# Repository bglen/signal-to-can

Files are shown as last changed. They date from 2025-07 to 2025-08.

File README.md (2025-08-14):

# signal-to-can device

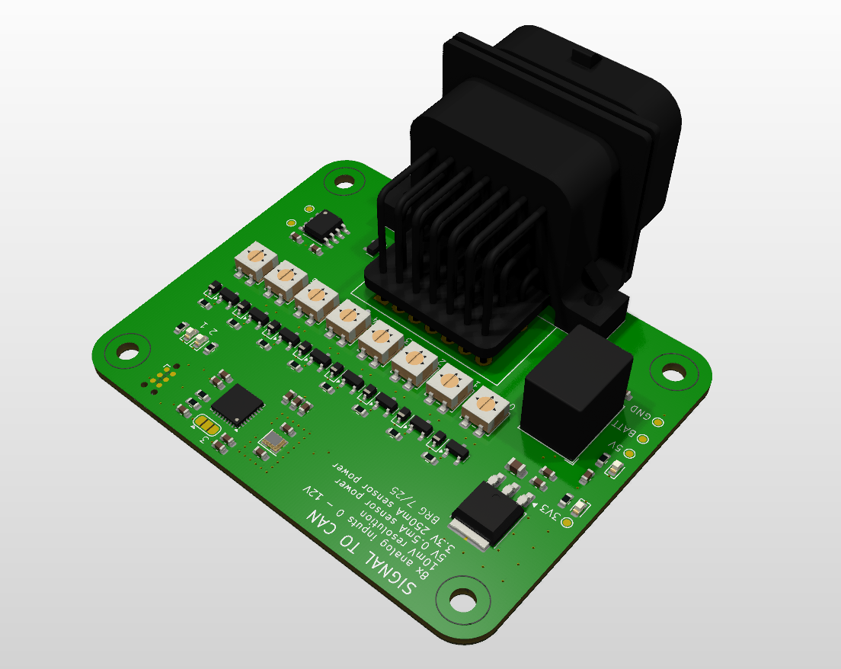
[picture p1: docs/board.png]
PCB view of device


Measures analog and digital signals and converts readings to CAN bus messages. Easilly powered by 12V automotive systems to make CAN bus datalogging in your vehicle easy.

- 8 ADC inputs with seperate signal grounds
  
- CAN 2.0b communication output
  
- Fully configurable through the CAN interface
  
- 3.3V and 5V sensor power supply
  
- Easilly powered by 12V automotive systems

- Per-channel configurable voltage offset and scaling

- Per-channel configurable out-of-range limits

- Pre-made DBC file you can use or edit as a template

### Enclosure

The repo contains a 3D-printable enclosure. We reccomend ASA, ABS, PC-ABS, or Nylon for automotive enviornments.

Front            |  Rear
:-------------------------:|:-------------------------:
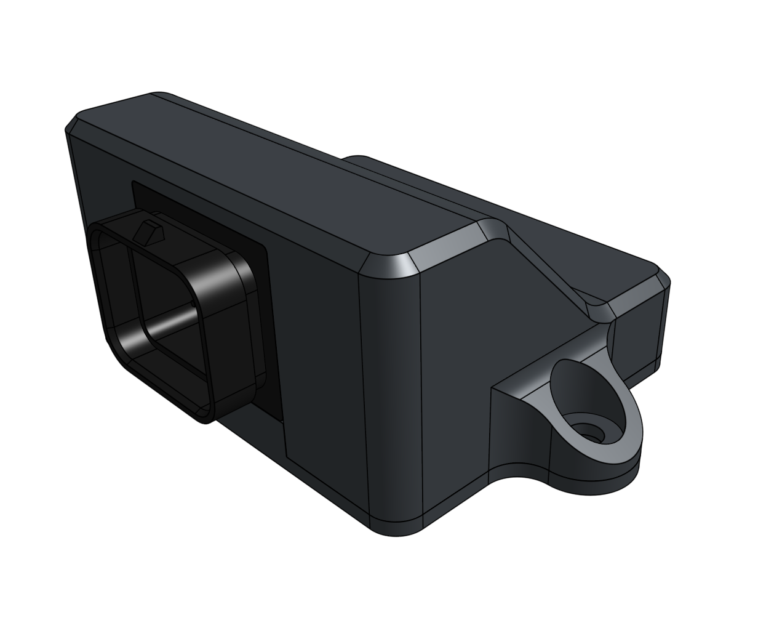
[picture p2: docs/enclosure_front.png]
Enclosure front
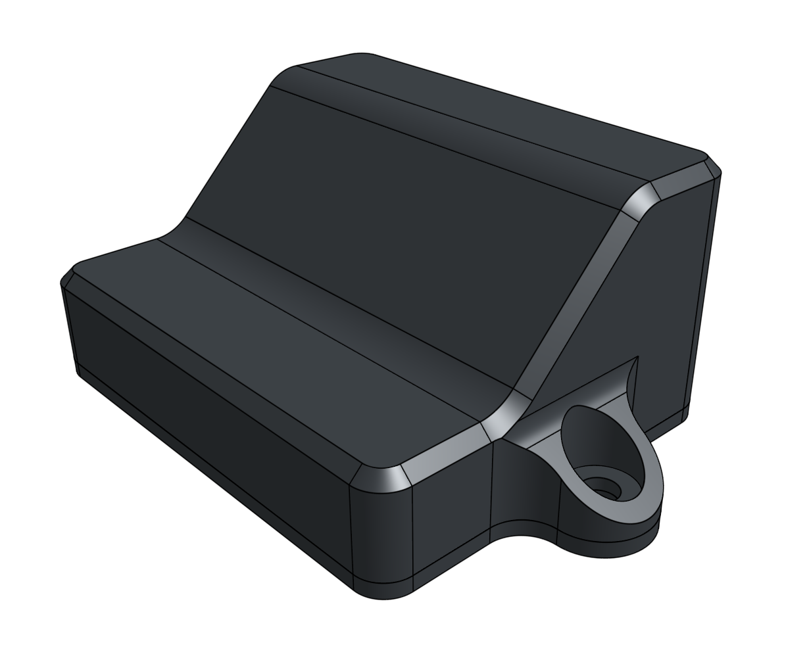
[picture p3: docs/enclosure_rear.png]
Enclosure rear
  |  

### TODO
- Update board with schematic changes
- Calibration test points
- Choose new potentiometer for rev 2
- configuration CAN message

# CAN Messages

All messages are big-endian (Motorola).

## Output Messages

| Name | ID | DLC | Bytes 0-1 | Bytes 2-3 | Bytes 4-5 | Bytes 6-7 |
| --- | --- | --- | --- | --- | --- | --- |
| ADC Values 0 - 3 | node_id + 0x1 | 8 bytes | adc_0 | adc_1 | adc_2 | adc_3 |
| ADC Values 4 - 7 | node_id + 0x2 | 8 bytes | adc_4 | adc_5 | adc_6 | adc_7 |

| Name | ID | DLC | Bytes 0-1  | Bytes 2-3 | Bytes 4-5 | Bytes 6-7  |
| --- | --- | --- | --- | --- | --- | --- |
| Device Status | node_id + 0x3 | 8 bytes | adc_status | uptime | v_supply  | fw_version |

### Parameters

**adc_0 to adc_7:** uint16, ontains the output value for each analog channel.

**adc_status:** uint16, Bit structure containing the current status for each channel. Each channel gets two bits starting with channel 0 to channel 7.

| 2-bit value  | Status |
| ---  | --- |
| 00 | Inactive |
| 01 | Active |
| 10 | Out-of-range low  |
| 11 | Out-of-range high |

Example: adc_satus = 00011001010111 -> channel 0 inactive, channel 1 active, channel 3 out-of-range low, channel 4 active, channel 5 active, channel 6 active, channel 7 out-of-range high.

**uptime:** uint16, Seconds since power-on, wraps at 65535.

**v_supply:** uint16, Device supply voltage in mV.

**fw_version** uint16, Device firmware version.

## Command Message

A single CAN ID is used for all command messages. The device will respond with an acknoledge message after receiving the command message.

| Name | ID | DLC | Byte 0  | Byte 1 | Byte 2 | Byte 3 | Byte 4 | Byte 5 | Byte 6 | Byte 7 |
| --- | --- | --- | --- | -----  | -----  | -----  | -----  | -----  | -----  | -----  |
| Command Message | node_id + 0x5 | 8 bytes | com | d1 | d2 | d3 | d4 | d5 | d6 | d7 |
| Ack Message | node_id + 0x6 | 1 bytes | success | | | | | | | |

### Command Codes

| Command Name | Command Code (com) | d1 | d2 | d3 | d4 | d5 | d6 | d7 |
| --- | --- | --- | --- | --- | --- | --- | --- | -- |
| SET_BAUD | 1 | baud_enum | 0 | 0 | 0 | 0 | 0 | 0  |
| SET_SAMPLE_RATE | 2 | sample_rate[0] | sample_rate[1] | 0 | 0 | 0 | 0 | 0  |
| SET_CHANNEL | 3 | channel | enable_bit | scale_factor[0] | scale_factor[1] | offset[0]  | offset[1] | 0  |
| SET_CHANNEL_RANGE  | 4 | channel | oor_min[0] | oor_min[1] | oor_max[0] | oor_max[1] | 0 | 0  |
| GET_VALUE | 5 | channel | selection | 0 | 0 | 0 | 0 | 0  |

### Parameters

**com:** uint8, Command code. Use the table below to specify a particular command and structure the data

**d1 to d5 :** unint8, Command-specific data.

**success:** uint8, 1 if command executed successfully, 0 if there was an error.

**baud_enum:** uint8, Enum representing the desired baud rate.

| baud_enum | Baud Rate |
| --- | --- |
| 0 | 125 kbps  |
| 1 | 250 kbps  |
| 2 | 500 kbps  |
| 3 | 1 Mbps |

**sample_rate:** uint16, Sample rate of the device in Hz. All channels are sampled at the same rate.

**channel:** uint8, Channel number from 0 to 7.

**enable_bit:** uint8, 0 -> inactive, 1 -> active.

**scale_factor:** uint16, Scale factor to convert the channel voltage to a useful value.

**offset:** uint16, Channel offset value, used with scale factor to convert the channel voltage to a useful value.

**oor_min:** uint16, Out of range minimum value. Used to detect issues with the channel, wiring, or sensor. Specify as a voltage in milivolts, from 0 to 3300. Must be less than the oor_max for that channel.

**oor_max:** uint16, Out of range maximum value. Used to detect issues with the channel, wiring, or sensor. Specify as a voltage in milivolts, from 0 to 3300.

**selection:** uint8, Enum representing the desired value to be returned.

| selection | Value to be returned |
| --- | --- |
| 0 | sample_rate |
| 1 | scale_factor |
| 2 | offset |
| 3 | oor_min |
| 4 | oor_max |

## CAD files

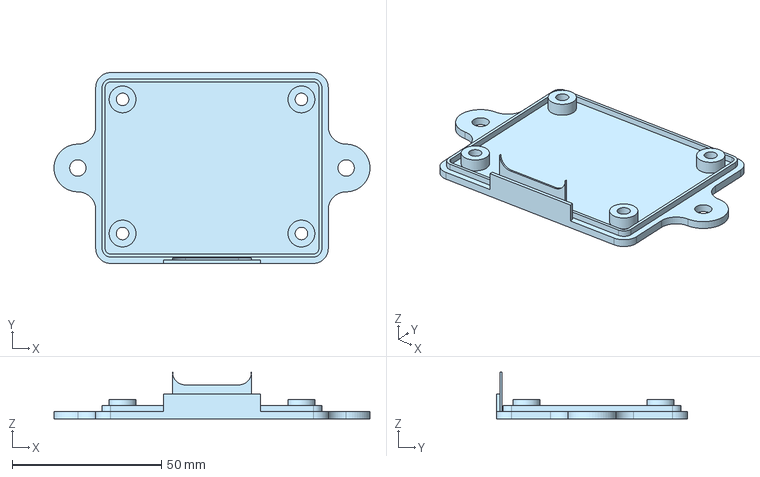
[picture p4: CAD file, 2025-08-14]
hardware/cad/base.step
106.0 x 64.0 x 15.7 mm

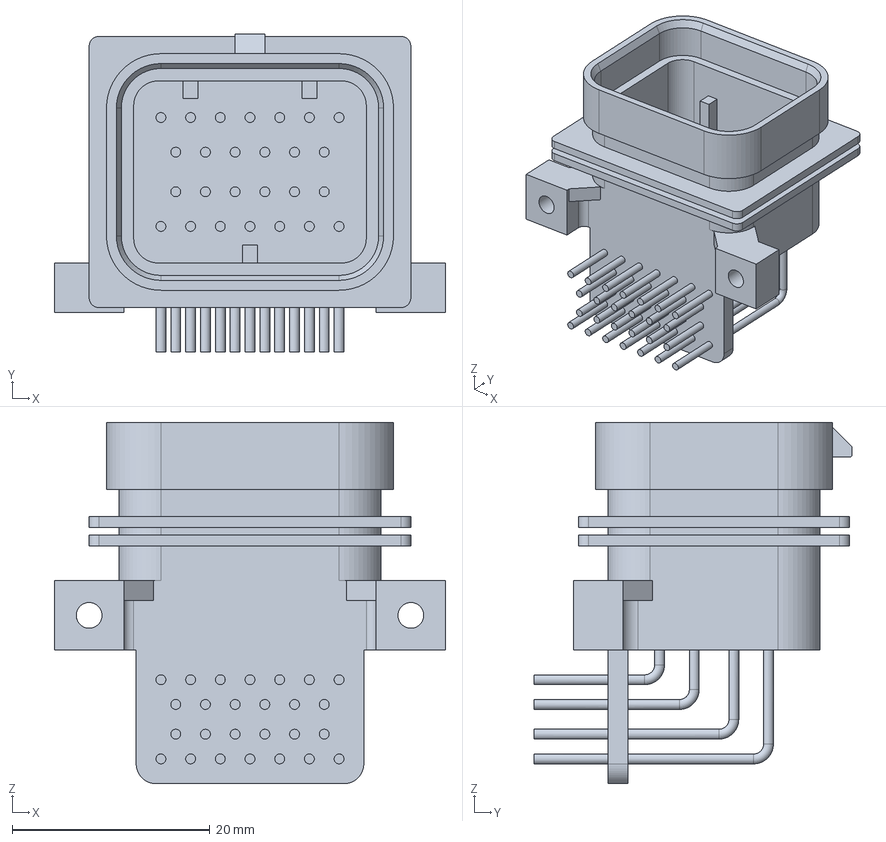
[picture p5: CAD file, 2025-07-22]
hardware/signal-to-can/3d_models/amp_superseal_9-6437287-8.step
39.5 x 32.1 x 36.5 mm

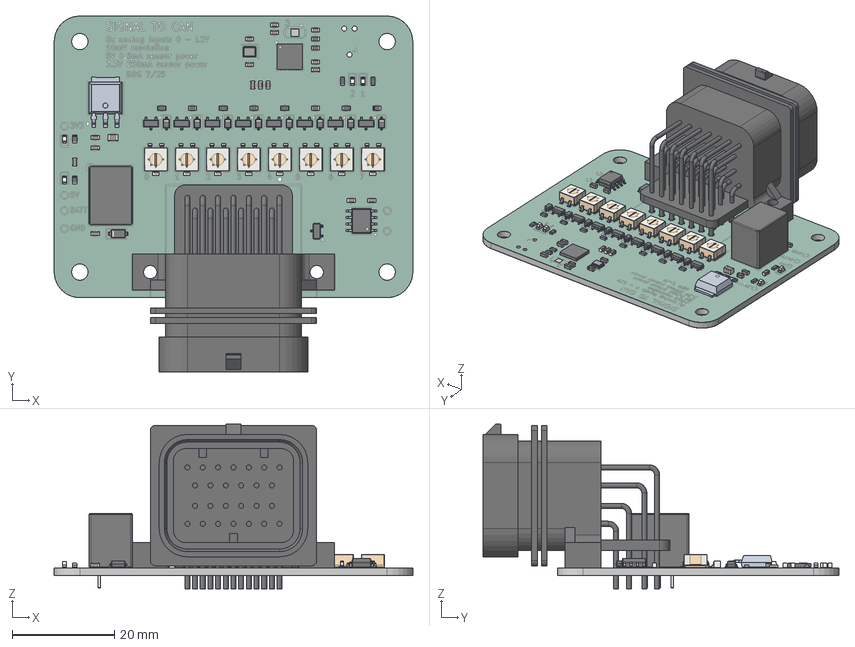
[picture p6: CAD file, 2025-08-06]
hardware/signal-to-can/signal-to-can.step
70.0 x 69.5 x 32.2 mm
D_SOD-323 x 8
Potentiometer_Bourns_3314G_Vertical x 8
LED_0603_1608Metric x 4
R_0603_1608Metric x 14
SOIC-8_3.9x4.9mm_P1.27mm
C_0603_1608Metric x 16
SOT-23 x 9
QFN-32-1EP_5x5mm_P0.5mm_EP3.45x3.45mm
D_SOD-123
C_0805_2012Metric
amp_superseal_9-6437287-8
signal-to-can 1.49.1
Crystal_SMD_2520-4Pin_2.5x2.0mm
Converter_DCDC_RECOM_R-78E-0.5_THT
signal-to-can_silkscreen
signal-to-can_soldermask
signal-to-can_PCB

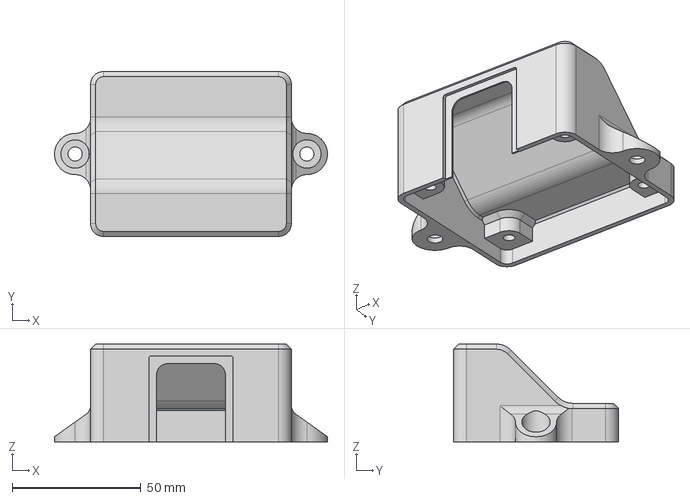
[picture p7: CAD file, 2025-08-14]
hardware/cad/lid.step
106.0 x 64.0 x 38.0 mm

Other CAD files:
hardware/cad/base.stl
hardware/cad/lid.stl

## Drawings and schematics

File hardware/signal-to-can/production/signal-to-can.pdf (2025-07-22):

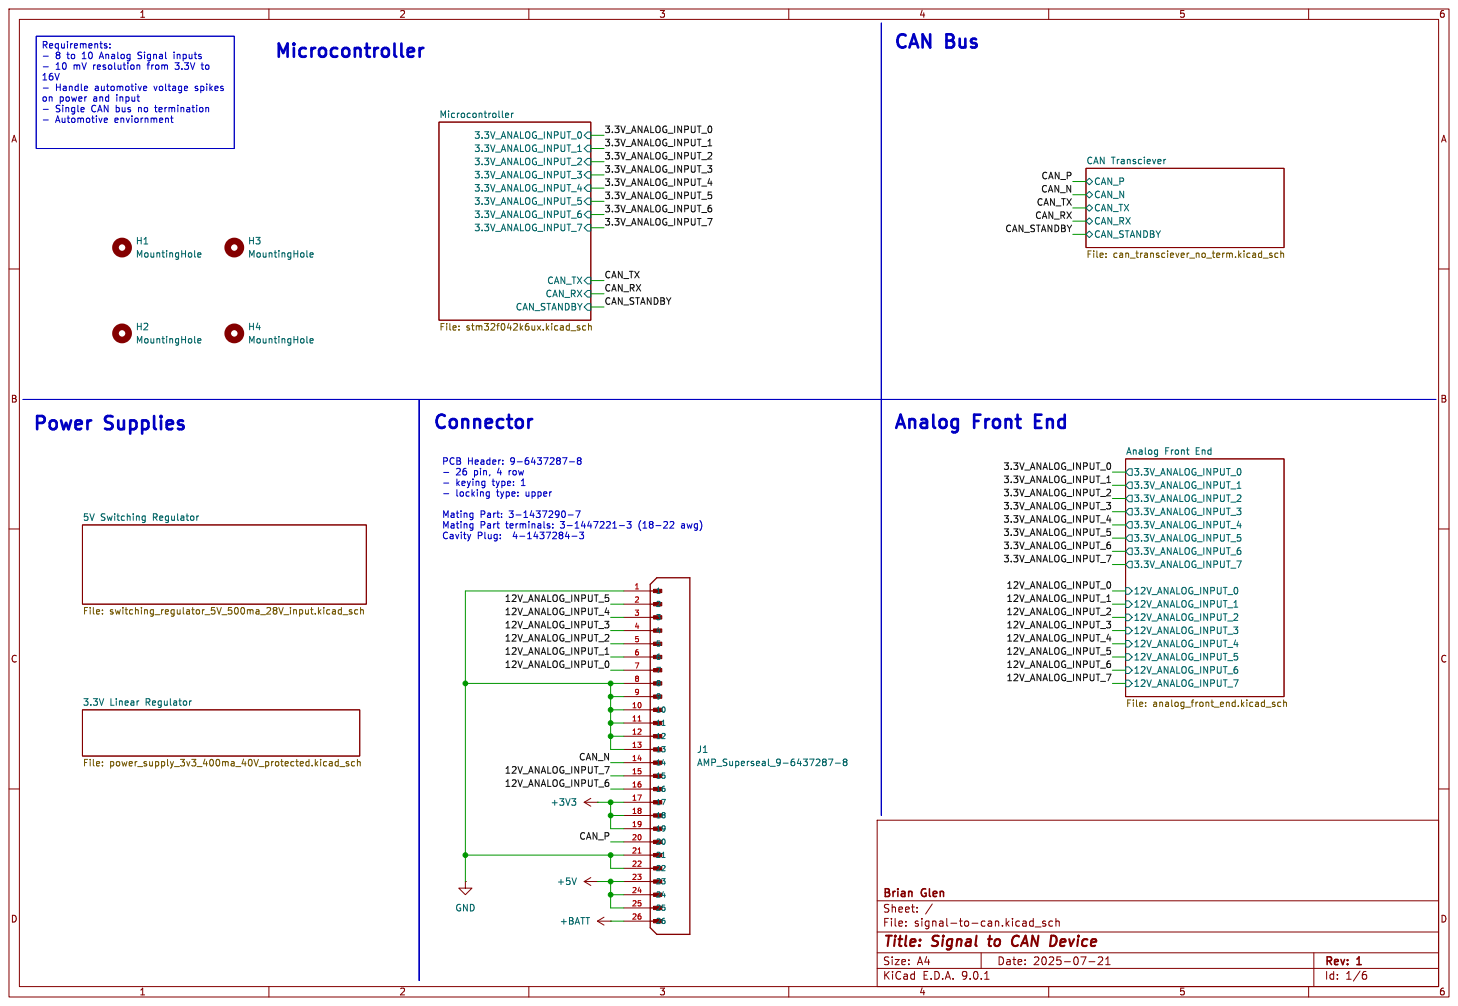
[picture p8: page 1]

3.3V_ANALOG_INPUT_1 Requirements: - 8 to 10 Analog Signal inputs

12V_ANALOG_INPUT_0 Analog Front End File: analog_front_end.kicad_sch +3V3 +BATT

File: signal-to-can.kicad_sch Sheet: / Brian Glen

Id: 1/6 Title: Signal to CAN Device

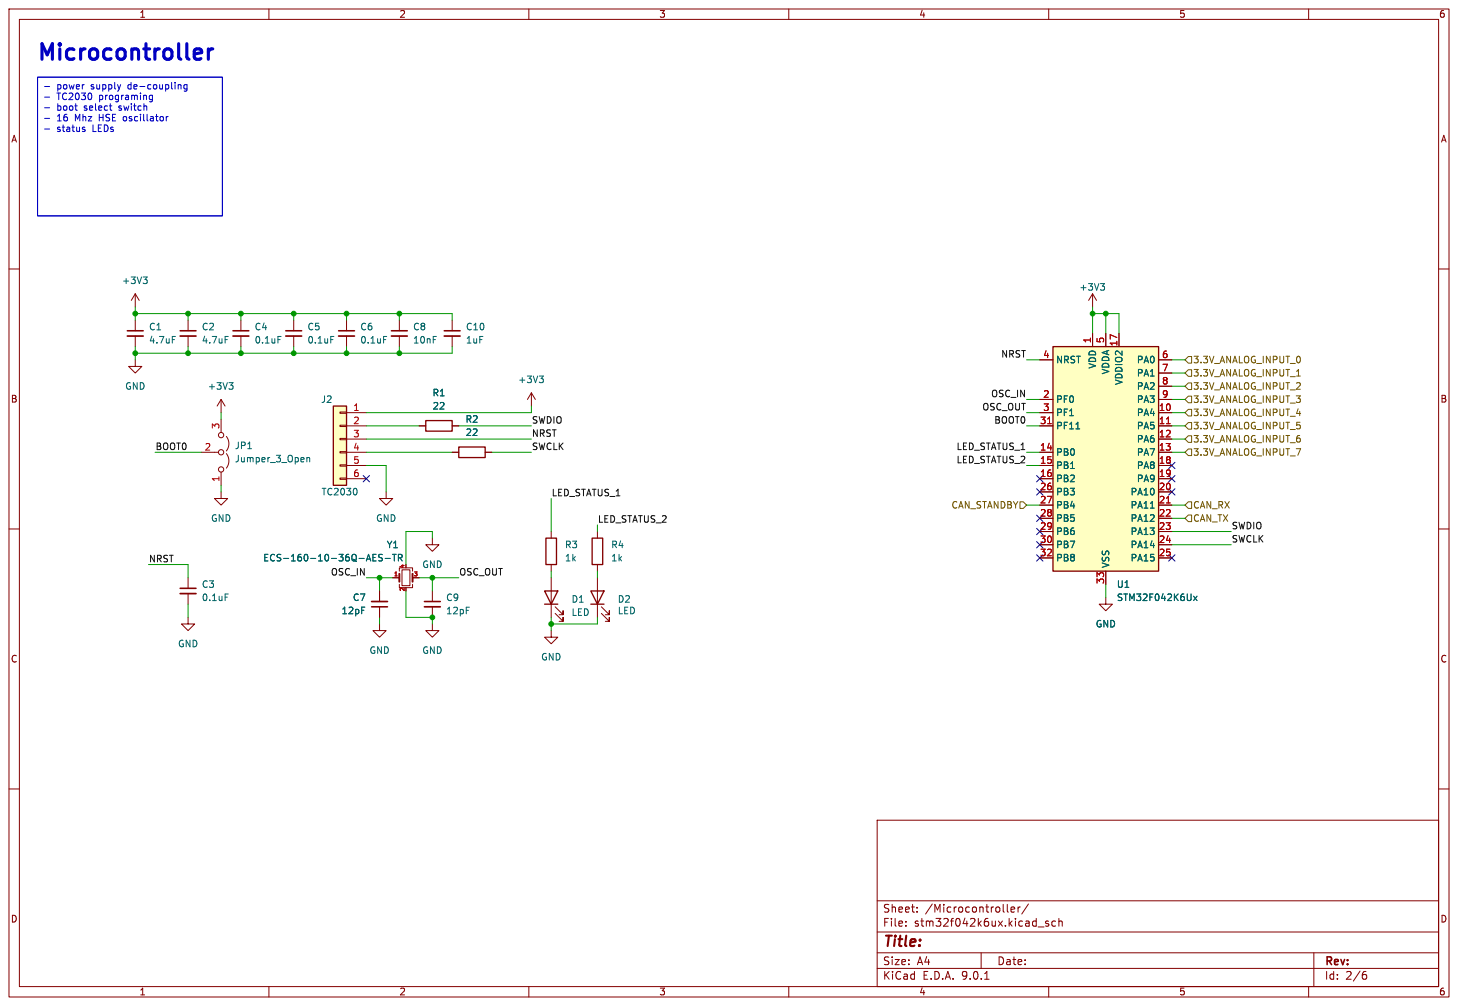
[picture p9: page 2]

- power supply de-coupling
- TC2030 programing
- boot select switch
- 16 Mhz HSE oscillator

Id: 2/6 Title: File: stm32f042k6ux.kicad_sch Sheet: /Microcontroller/

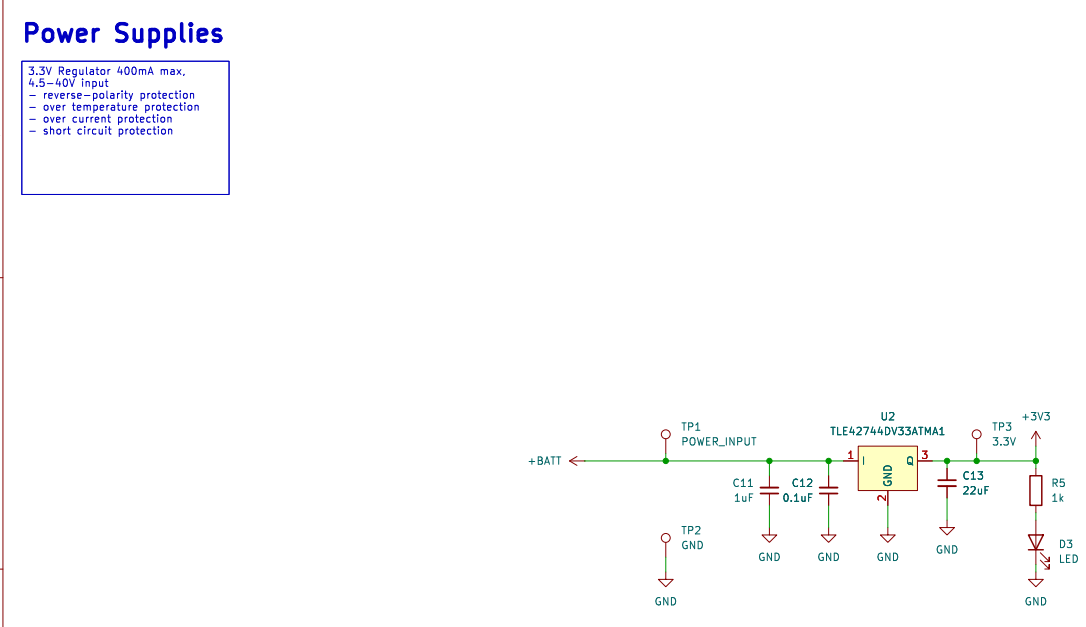
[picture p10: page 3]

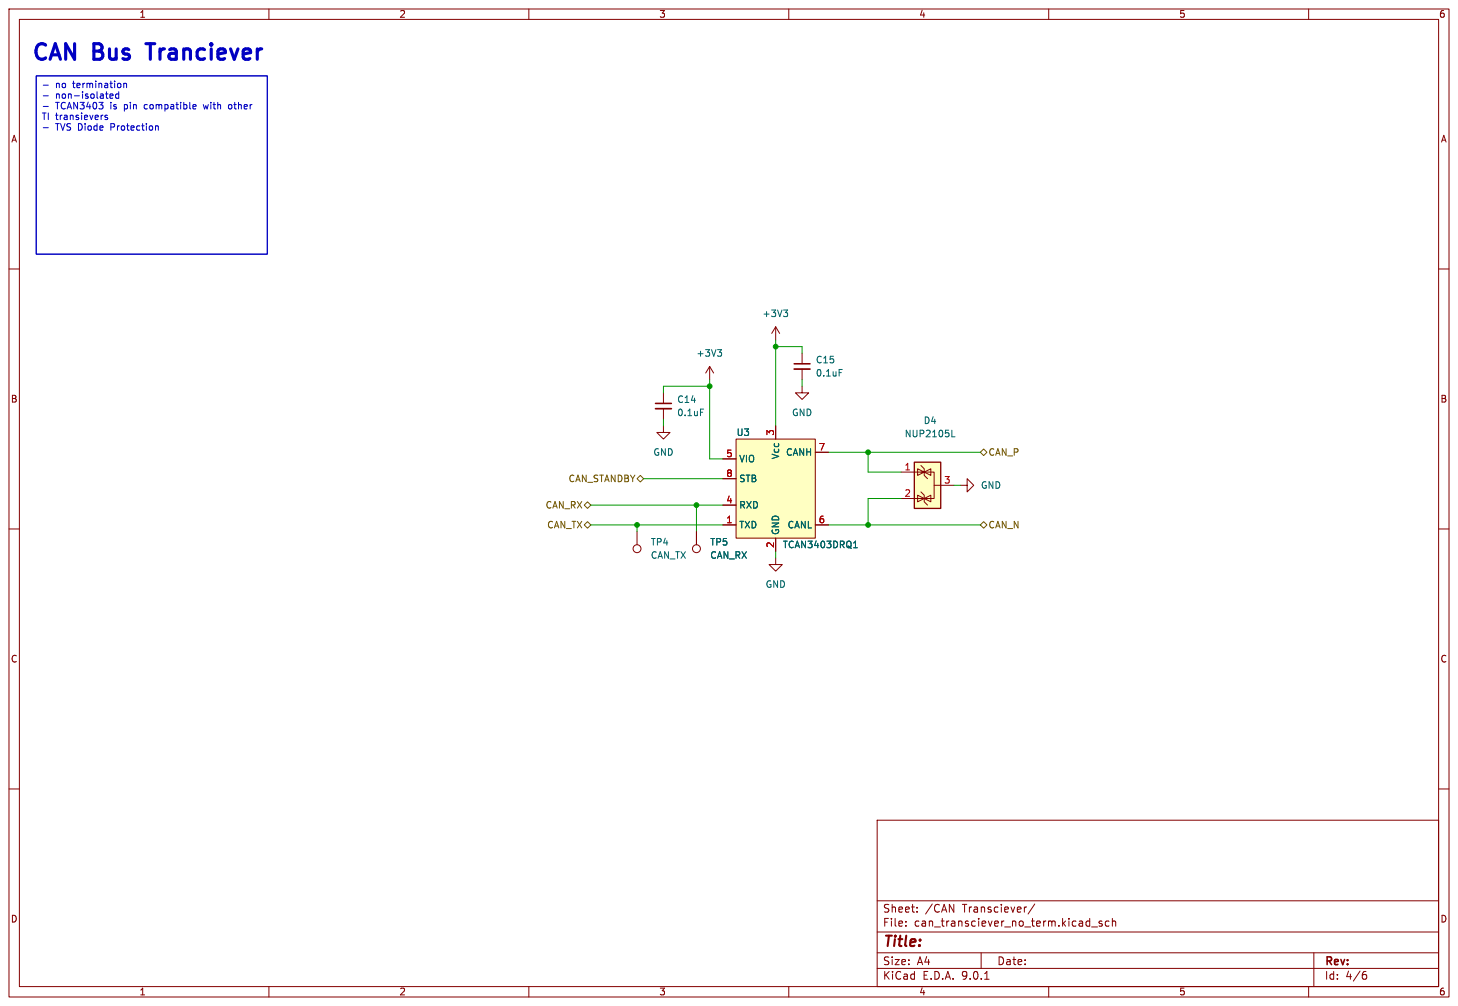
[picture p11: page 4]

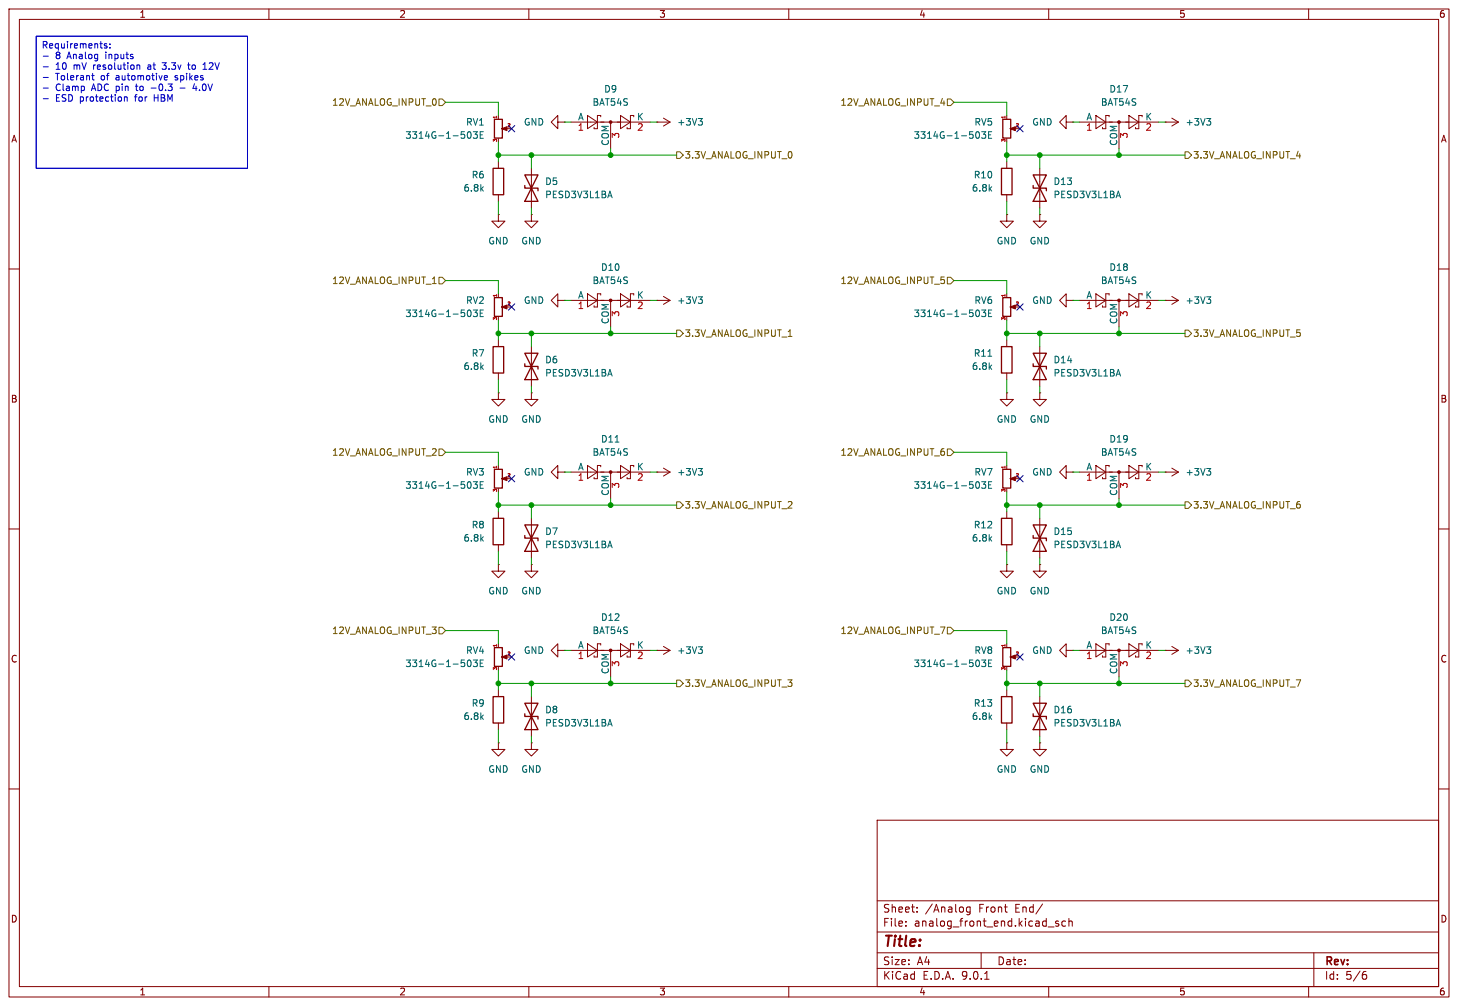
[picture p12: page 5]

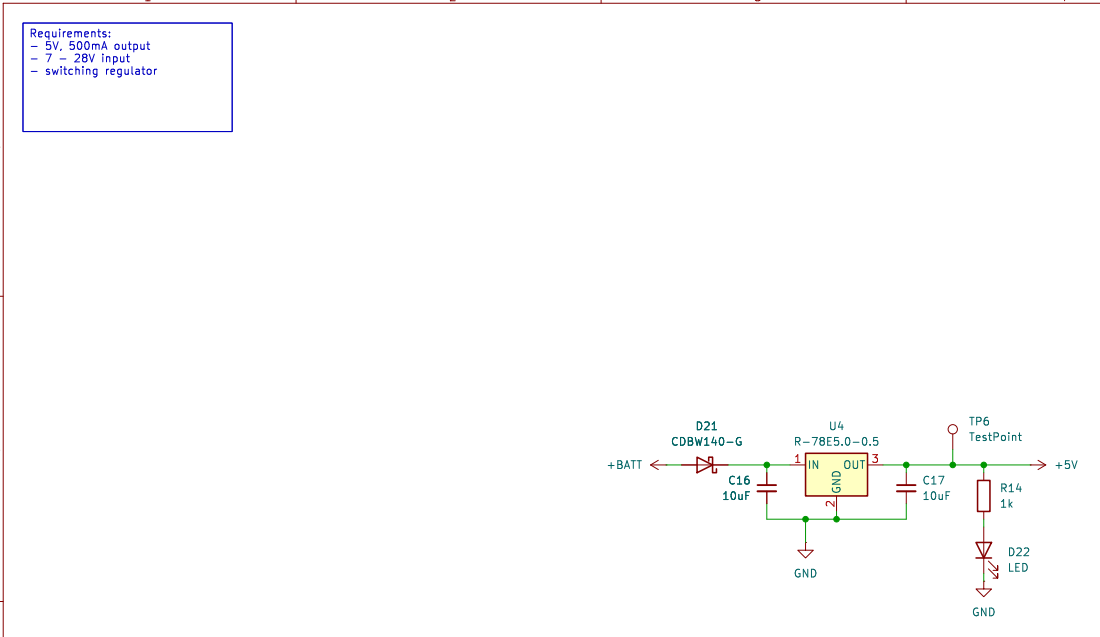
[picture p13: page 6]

2 OUT 3 U4 R-78E5.0-0.5 TP6 TestPoint Requirements: - 5V, 500mA output - 7 - 28V input - switching regulator D21 CDBW140-G

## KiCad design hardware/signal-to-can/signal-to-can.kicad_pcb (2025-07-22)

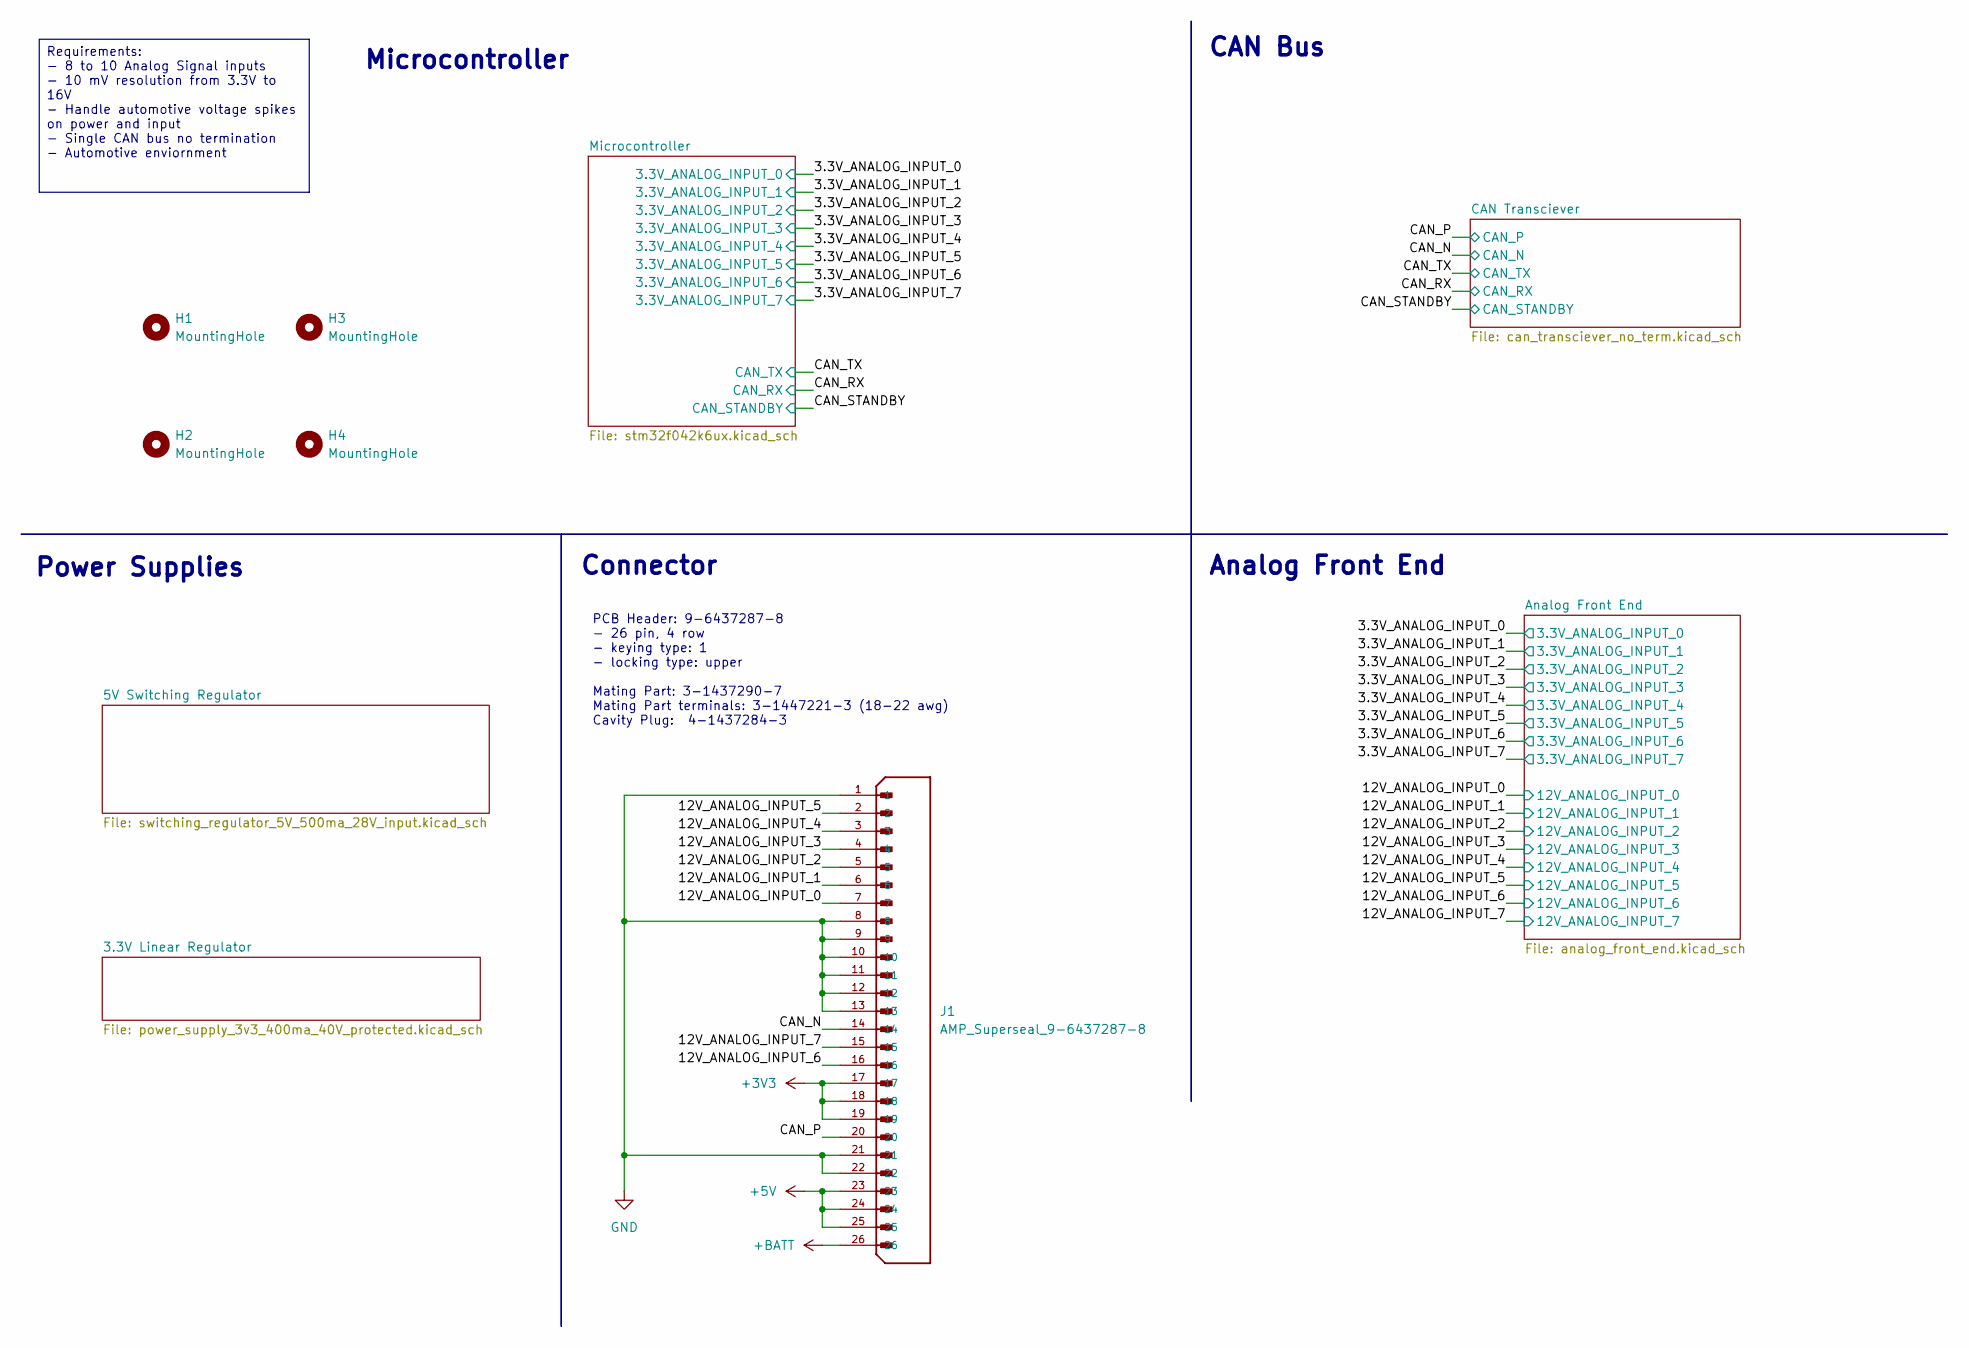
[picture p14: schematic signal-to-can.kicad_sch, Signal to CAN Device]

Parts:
H1, H2, H3, H4: MountingHole; MountingHole_3.2mm_M3
J1: AMP_Superseal_9-6437287-8; TE_9-6437287-8_1; PARTREV A1

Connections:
+3V3: J1.17, J1.18, J1.19; also elsewhere on the board
+5V: J1.23, J1.24, J1.25; also elsewhere on the board
+BATT: J1.26; also elsewhere on the board
/12V_ANALOG_INPUT_0: J1.7; also elsewhere on the board
/12V_ANALOG_INPUT_1: J1.6; also elsewhere on the board
/12V_ANALOG_INPUT_2: J1.5; also elsewhere on the board
/12V_ANALOG_INPUT_3: J1.4; also elsewhere on the board
/12V_ANALOG_INPUT_4: J1.3; also elsewhere on the board
/12V_ANALOG_INPUT_5: J1.2; also elsewhere on the board
/12V_ANALOG_INPUT_6: J1.16; also elsewhere on the board
/12V_ANALOG_INPUT_7: J1.15; also elsewhere on the board
/CAN_N: J1.14; also elsewhere on the board
/CAN_P: J1.20; also elsewhere on the board
GND: J1.1, J1.8, J1.9, J1.10, J1.11, J1.12, J1.13, J1.21, J1.22; also elsewhere on the board

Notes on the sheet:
Connector
Analog Front End
PCB Header: 9-6437287-8 - 26 pin, 4 row - keying type: 1 - locking type: upper Mating Part: 3-1437290-7 Mating Part terminals: 3-1447221-3 (18-22 awg) Cavity Plug: 4-1437284-3
Power Supplies
CAN Bus
Microcontroller
Requirements: - 8 to 10 Analog Signal inputs - 10 mV resolution from 3.3V to 16V - Handle automotive voltage spikes on power and input - Single CAN bus no termination - Automotive enviornment

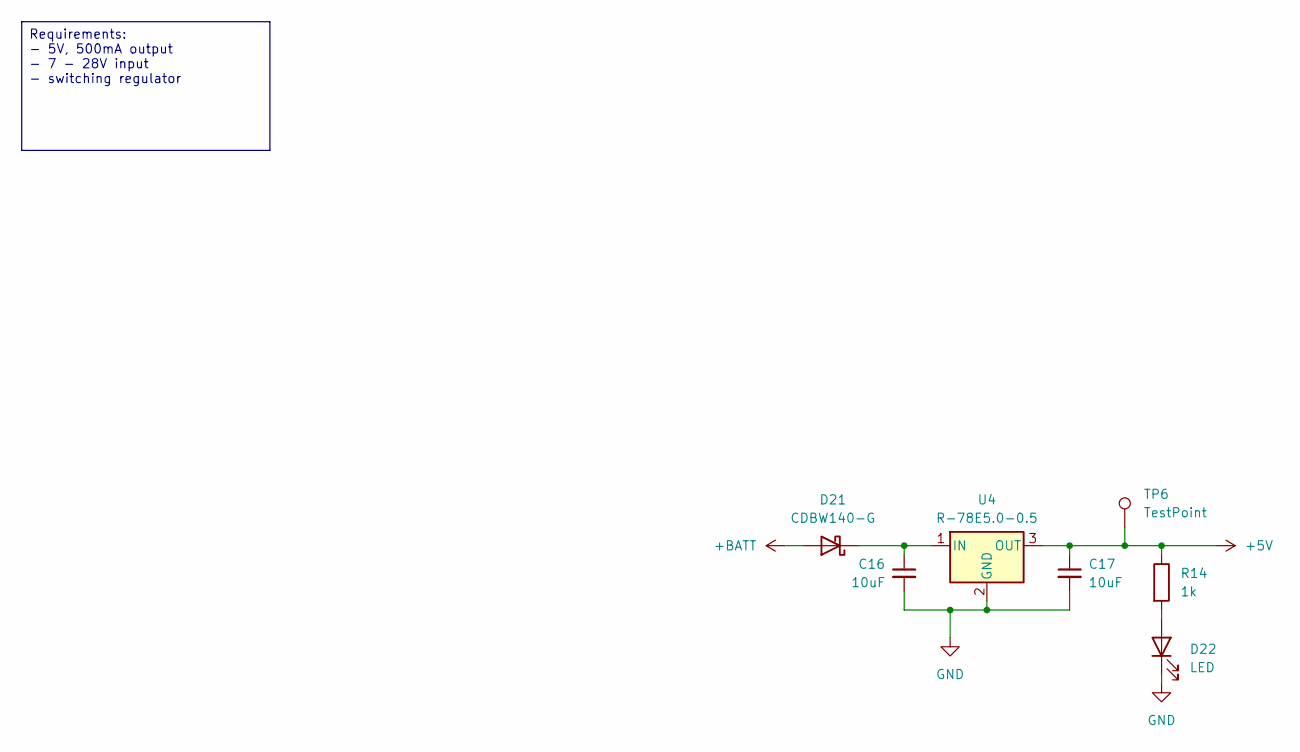
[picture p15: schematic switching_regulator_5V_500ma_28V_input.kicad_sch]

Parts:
C16, C17: 10uF; C_0603_1608Metric
D21: CDBW140-G; D_SOD-123
D22: LED; LED_0603_1608Metric
R14: 1k; R_0603_1608Metric
TP6: TestPoint; TestPoint_Pad_D1.0mm
U4: R-78E5.0-0.5; Converter_DCDC_RECOM_R-78E-0.5_THT

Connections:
+5V: C17.1, R14.1, TP6.1, U4.3 (OUT); also elsewhere on the board
+BATT: D21.2 (A); also elsewhere on the board
GND: C16.2, C17.2, D22.1 (K), U4.2 (GND); also elsewhere on the board
unnamed: C16.1, D21.1 (K), U4.1 (IN)
unnamed: D22.2 (A), R14.2

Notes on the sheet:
Requirements: - 5V, 500mA output - 7 - 28V input - switching regulator

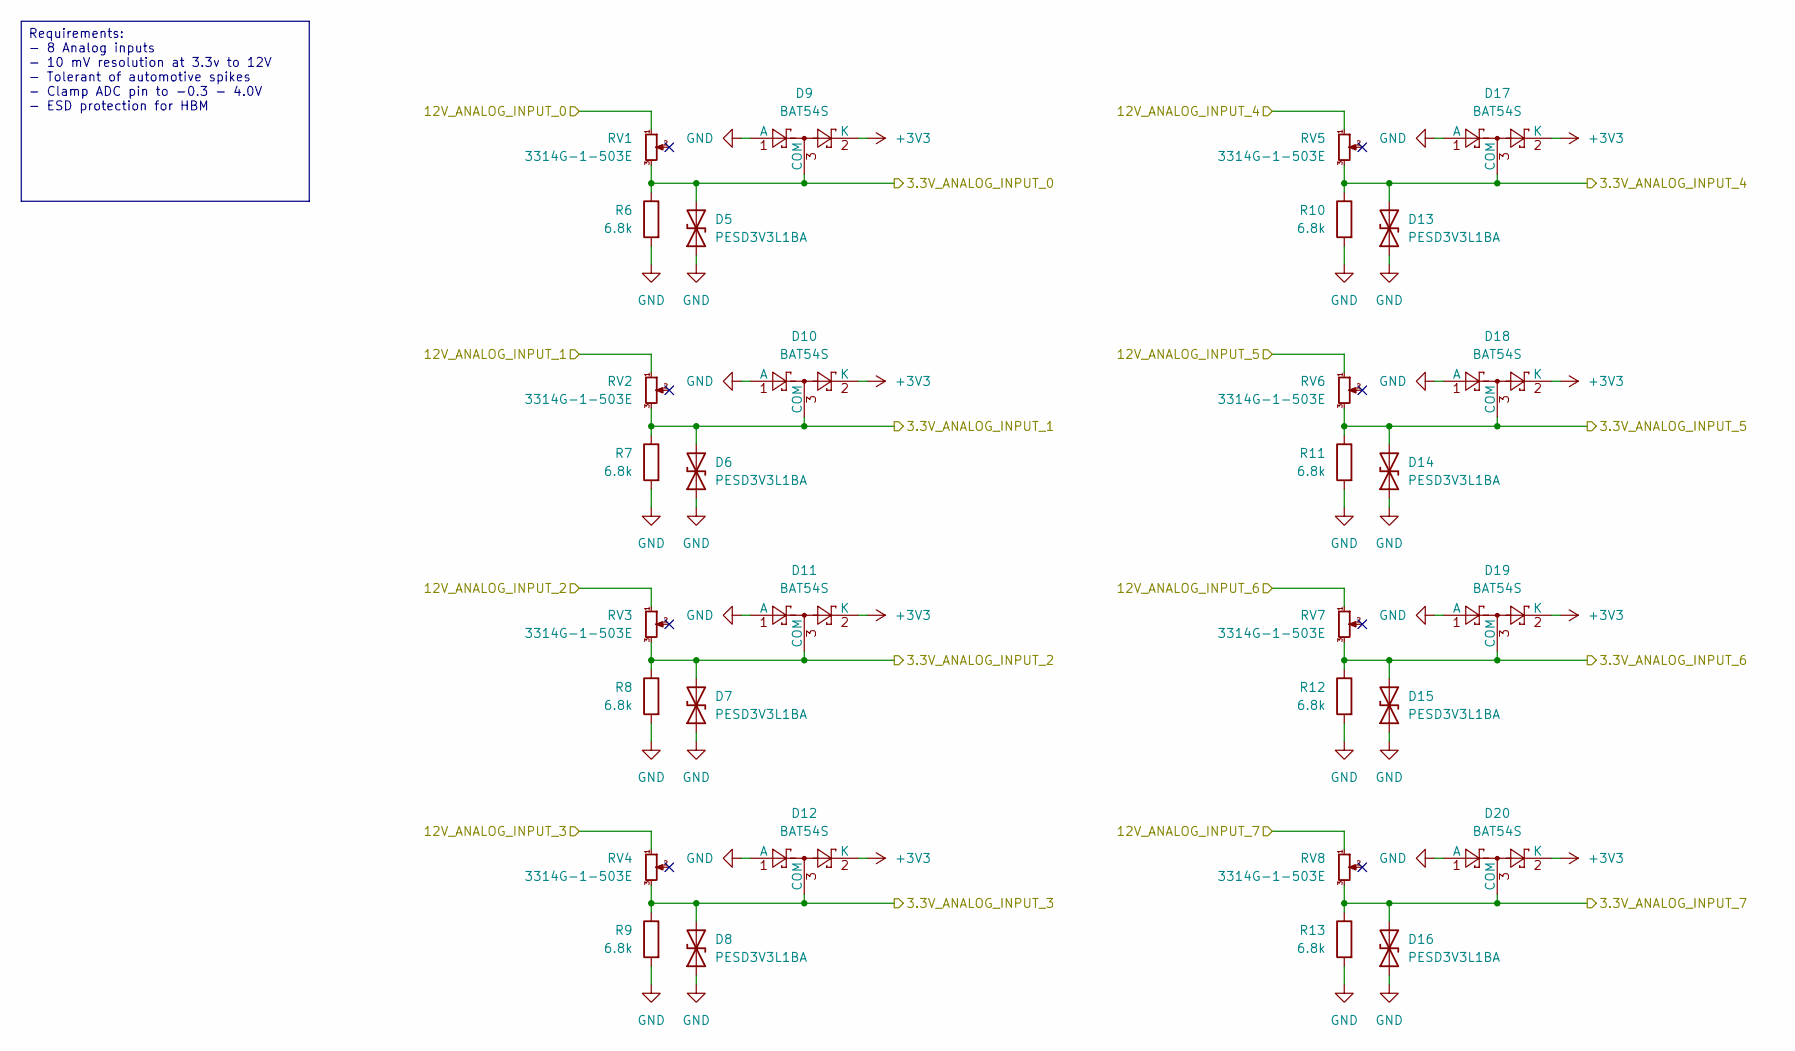
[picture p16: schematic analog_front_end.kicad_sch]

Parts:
D5, D6, D7, D8, D13, D14, D15, D16: PESD3V3L1BA; D_SOD-323
D9, D10, D11, D12, D17, D18, D19, D20: BAT54S; SOT-23
R6, R7, R8, R9, R10, R11, R12, R13: 6.8k; R_0603_1608Metric
RV1, RV2, RV3, RV4, RV5, RV6, RV7, RV8: 3314G-1-503E; Potentiometer_Bourns_3314G_Vertical

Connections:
+3V3: D9.2 (K), D10.2 (K), D11.2 (K), D12.2 (K), D17.2 (K), D18.2 (K), D19.2 (K), D20.2 (K); also elsewhere on the board
/3.3V_ANALOG_INPUT_0: D5.2 (A2), D9.3 (COM), R6.1, RV1.3; also elsewhere on the board
/3.3V_ANALOG_INPUT_1: D6.2 (A2), D10.3 (COM), R7.1, RV2.3; also elsewhere on the board
/3.3V_ANALOG_INPUT_2: D7.2 (A2), D11.3 (COM), R8.1, RV3.3; also elsewhere on the board
/3.3V_ANALOG_INPUT_3: D8.2 (A2), D12.3 (COM), R9.1, RV4.3; also elsewhere on the board
/3.3V_ANALOG_INPUT_4: D13.2 (A2), D17.3 (COM), R10.1, RV5.3; also elsewhere on the board
/3.3V_ANALOG_INPUT_5: D14.2 (A2), D18.3 (COM), R11.1, RV6.3; also elsewhere on the board
/3.3V_ANALOG_INPUT_6: D15.2 (A2), D19.3 (COM), R12.1, RV7.3; also elsewhere on the board
/3.3V_ANALOG_INPUT_7: D16.2 (A2), D20.3 (COM), R13.1, RV8.3; also elsewhere on the board
/12V_ANALOG_INPUT_0: RV1.1; also elsewhere on the board
/12V_ANALOG_INPUT_1: RV2.1; also elsewhere on the board
/12V_ANALOG_INPUT_2: RV3.1; also elsewhere on the board
/12V_ANALOG_INPUT_3: RV4.1; also elsewhere on the board
/12V_ANALOG_INPUT_4: RV5.1; also elsewhere on the board
/12V_ANALOG_INPUT_5: RV6.1; also elsewhere on the board
/12V_ANALOG_INPUT_6: RV7.1; also elsewhere on the board
/12V_ANALOG_INPUT_7: RV8.1; also elsewhere on the board
GND: D5.1 (A1), D6.1 (A1), D7.1 (A1), D8.1 (A1), D9.1 (A), D10.1 (A), D11.1 (A), D12.1 (A), D13.1 (A1), D14.1 (A1), D15.1 (A1), D16.1 (A1), D17.1 (A), D18.1 (A), D19.1 (A), D20.1 (A), R6.2, R7.2, R8.2, R9.2, R10.2, R11.2, R12.2, R13.2; also elsewhere on the board

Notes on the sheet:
Requirements: - 8 Analog inputs - 10 mV resolution at 3.3v to 12V - Tolerant of automotive spikes - Clamp ADC pin to -0.3 - 4.0V - ESD protection for HBM

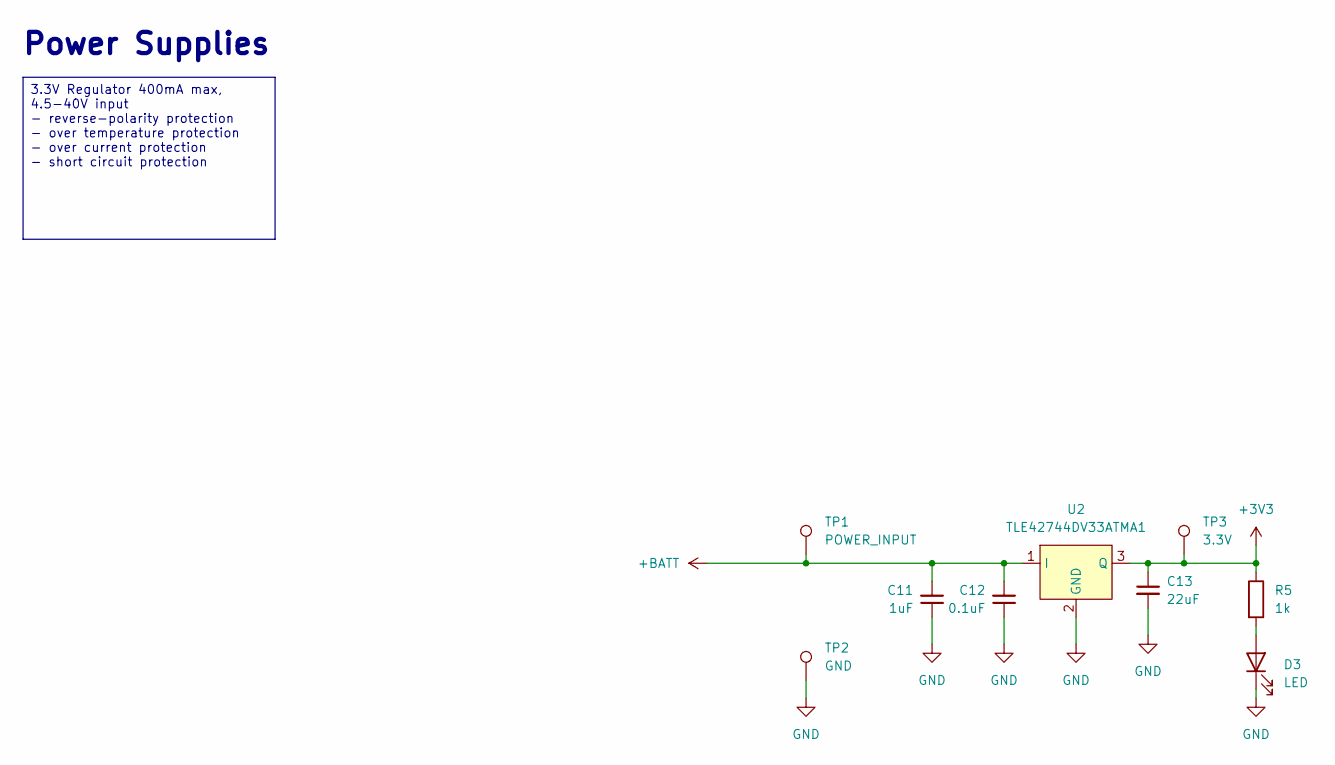
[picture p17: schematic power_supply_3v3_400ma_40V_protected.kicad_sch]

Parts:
C11: 1uF; C_0603_1608Metric
C12: 0.1uF; C_0603_1608Metric
C13: 22uF; C_0805_2012Metric
D3: LED; LED_0603_1608Metric
R5: 1k; R_0603_1608Metric
TP1: POWER_INPUT; TestPoint_Pad_D1.0mm
TP2: GND; TestPoint_Pad_D1.0mm
TP3: 3.3V; TestPoint_Pad_D1.0mm
U2: TLE42744DV33ATMA1; TO-252-3_TabPin2

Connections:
+3V3: C13.1, R5.1, TP3.1, U2.3 (Q); also elsewhere on the board
+BATT: C11.2, C12.2, TP1.1, U2.1 (I); also elsewhere on the board
GND: C11.1, C12.1, C13.2, D3.1 (K), TP2.1, U2.2 (GND); also elsewhere on the board
unnamed: D3.2 (A), R5.2

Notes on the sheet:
Power Supplies
3.3V Regulator 400mA max, 4.5-40V input - reverse-polarity protection - over temperature protection - over current protection - short circuit protection

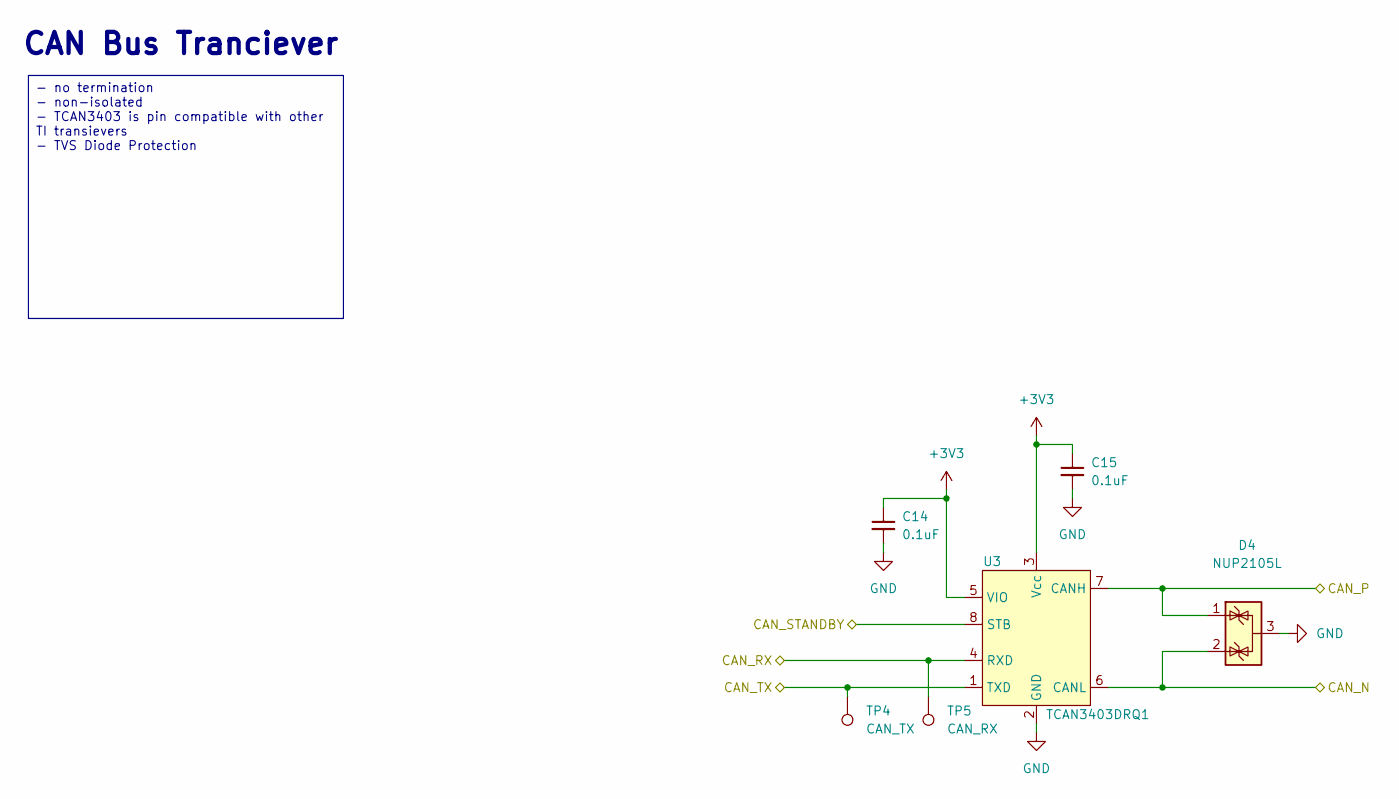
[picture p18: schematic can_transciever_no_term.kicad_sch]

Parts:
C14, C15: 0.1uF; C_0603_1608Metric
D4: NUP2105L; SOT-23
TP4: CAN_TX; TestPoint_Pad_D1.0mm
TP5: CAN_RX; TestPoint_Pad_D1.0mm
U3: TCAN3403DRQ1; SOIC-8_3.9x4.9mm_P1.27mm

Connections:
+3V3: C14.1, C15.1, U3.3 (Vcc), U3.5 (VIO); also elsewhere on the board
/CAN_N: D4.2 (K), U3.6 (CANL); also elsewhere on the board
/CAN_P: D4.1 (K), U3.7 (CANH); also elsewhere on the board
/CAN_RX: TP5.1, U3.4 (RXD); also elsewhere on the board
/CAN_STANDBY: U3.8 (STB); also elsewhere on the board
/CAN_TX: TP4.1, U3.1 (TXD); also elsewhere on the board
GND: C14.2, C15.2, D4.3 (A), U3.2 (GND); also elsewhere on the board

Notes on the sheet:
CAN Bus Tranciever
- no termination - non-isolated - TCAN3403 is pin compatible with other TI transievers - TVS Diode Protection

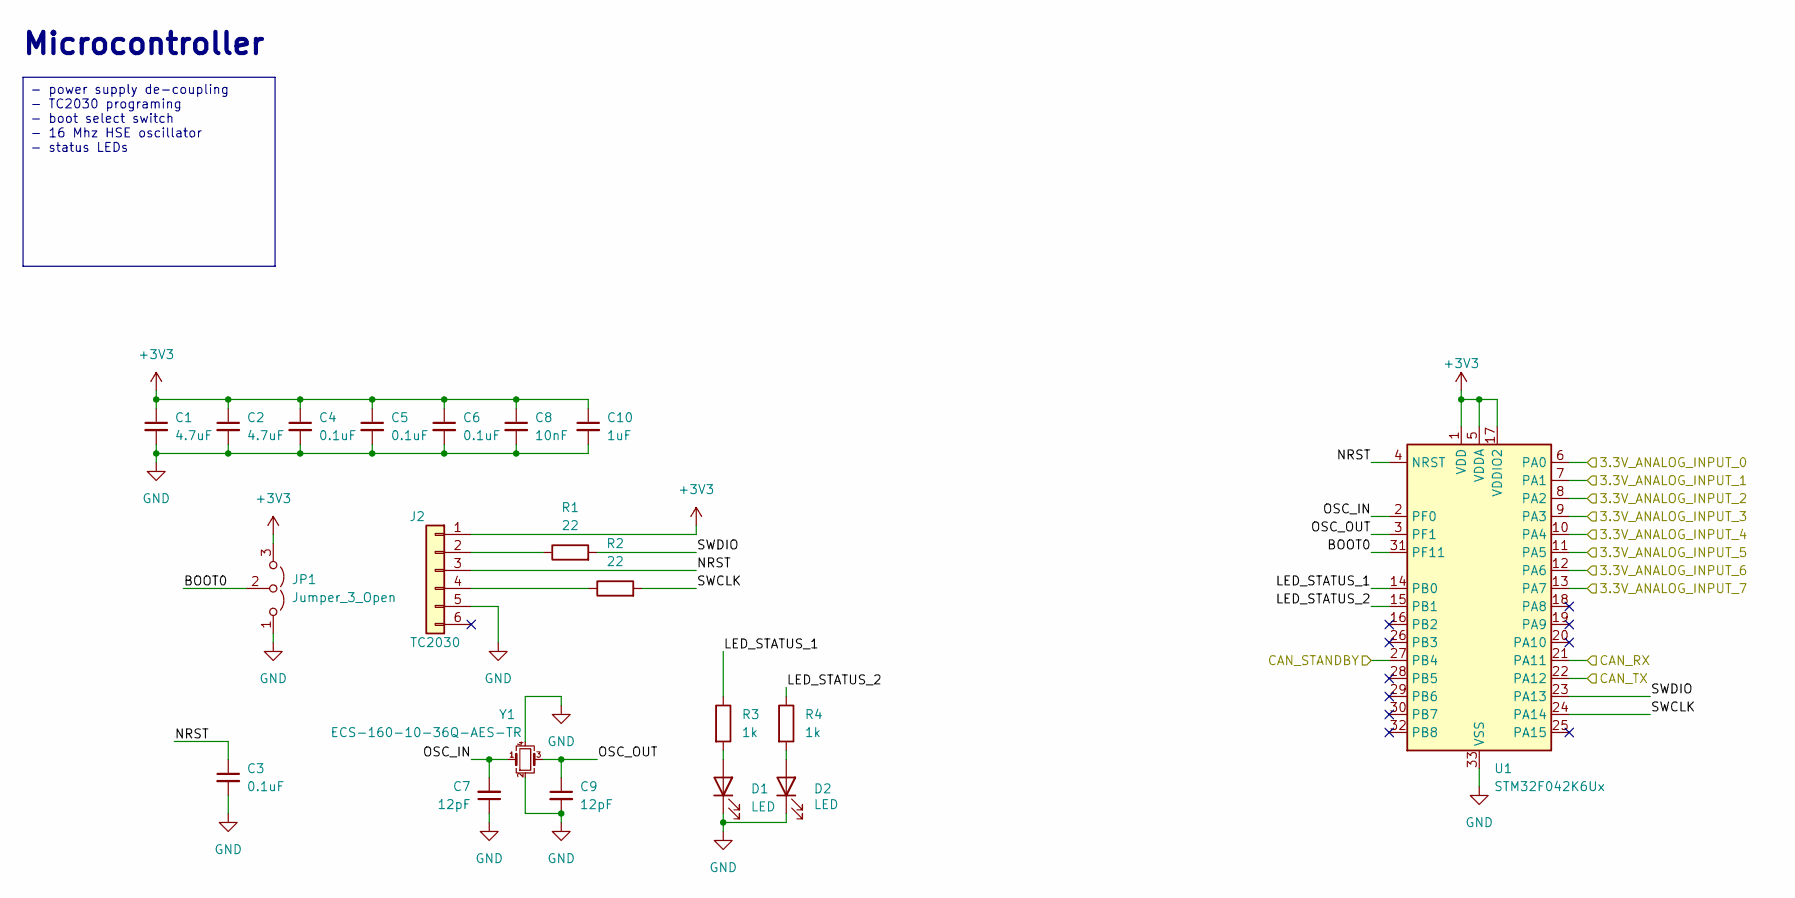
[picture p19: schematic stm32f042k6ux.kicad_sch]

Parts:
C1, C2: 4.7uF; C_0603_1608Metric
C3, C4, C5, C6: 0.1uF; C_0603_1608Metric
C7, C9: 12pF; C_0603_1608Metric
C8: 10nF; C_0603_1608Metric
C10: 1uF; C_0603_1608Metric
D1, D2: LED; LED_0603_1608Metric
J2: TC2030; Tag-Connect_TC2030-IDC-NL_2x03_P1.27mm_Vertical
JP1: Jumper_3_Open; SolderJumper-3_P1.3mm_Open_RoundedPad1.0x1.5mm
R1, R2: 22; R_0603_1608Metric
R3, R4: 1k; R_0603_1608Metric
U1: STM32F042K6Ux; QFN-32-1EP_5x5mm_P0.5mm_EP3.45x3.45mm
Y1: ECS-160-10-36Q-AES-TR; Crystal_SMD_2520-4Pin_2.5x2.0mm

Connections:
+3V3: C1.1, C2.1, C4.1, C5.1, C6.1, C8.1, C10.1, J2.1, JP1.3 (B), U1.1 (VDD), U1.5 (VDDA), U1.17 (VDDIO2); also elsewhere on the board
/3.3V_ANALOG_INPUT_0: U1.6 (PA0); also elsewhere on the board
/3.3V_ANALOG_INPUT_1: U1.7 (PA1); also elsewhere on the board
/3.3V_ANALOG_INPUT_2: U1.8 (PA2); also elsewhere on the board
/3.3V_ANALOG_INPUT_3: U1.9 (PA3); also elsewhere on the board
/3.3V_ANALOG_INPUT_4: U1.10 (PA4); also elsewhere on the board
/3.3V_ANALOG_INPUT_5: U1.11 (PA5); also elsewhere on the board
/3.3V_ANALOG_INPUT_6: U1.12 (PA6); also elsewhere on the board
/3.3V_ANALOG_INPUT_7: U1.13 (PA7); also elsewhere on the board
/CAN_RX: U1.21 (PA11); also elsewhere on the board
/CAN_STANDBY: U1.27 (PB4); also elsewhere on the board
/CAN_TX: U1.22 (PA12); also elsewhere on the board
/Microcontroller/BOOT0: JP1.2 (C), U1.31 (PF11)
/Microcontroller/LED_STATUS_1: R3.1, U1.14 (PB0)
/Microcontroller/LED_STATUS_2: R4.1, U1.15 (PB1)
/Microcontroller/NRST: C3.1, J2.3, U1.4 (NRST)
/Microcontroller/OSC_IN: C7.2, U1.2 (PF0), Y1.1
/Microcontroller/OSC_OUT: C9.1, U1.3 (PF1), Y1.3
/Microcontroller/SWCLK: R2.2, U1.24 (PA14)
/Microcontroller/SWDIO: R1.2, U1.23 (PA13)
GND: C1.2, C2.2, C3.2, C4.2, C5.2, C6.2, C7.1, C8.2, C9.2, C10.2, D1.1 (K), D2.1 (K), J2.5, JP1.1 (A), U1.33 (VSS), Y1.2, Y1.4; also elsewhere on the board
unnamed: D1.2 (A), R3.2
unnamed: D2.2 (A), R4.2
unnamed: J2.2, R1.1
unnamed: J2.4, R2.1

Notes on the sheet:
Microcontroller
- power supply de-coupling - TC2030 programing - boot select switch - 16 Mhz HSE oscillator - status LEDs

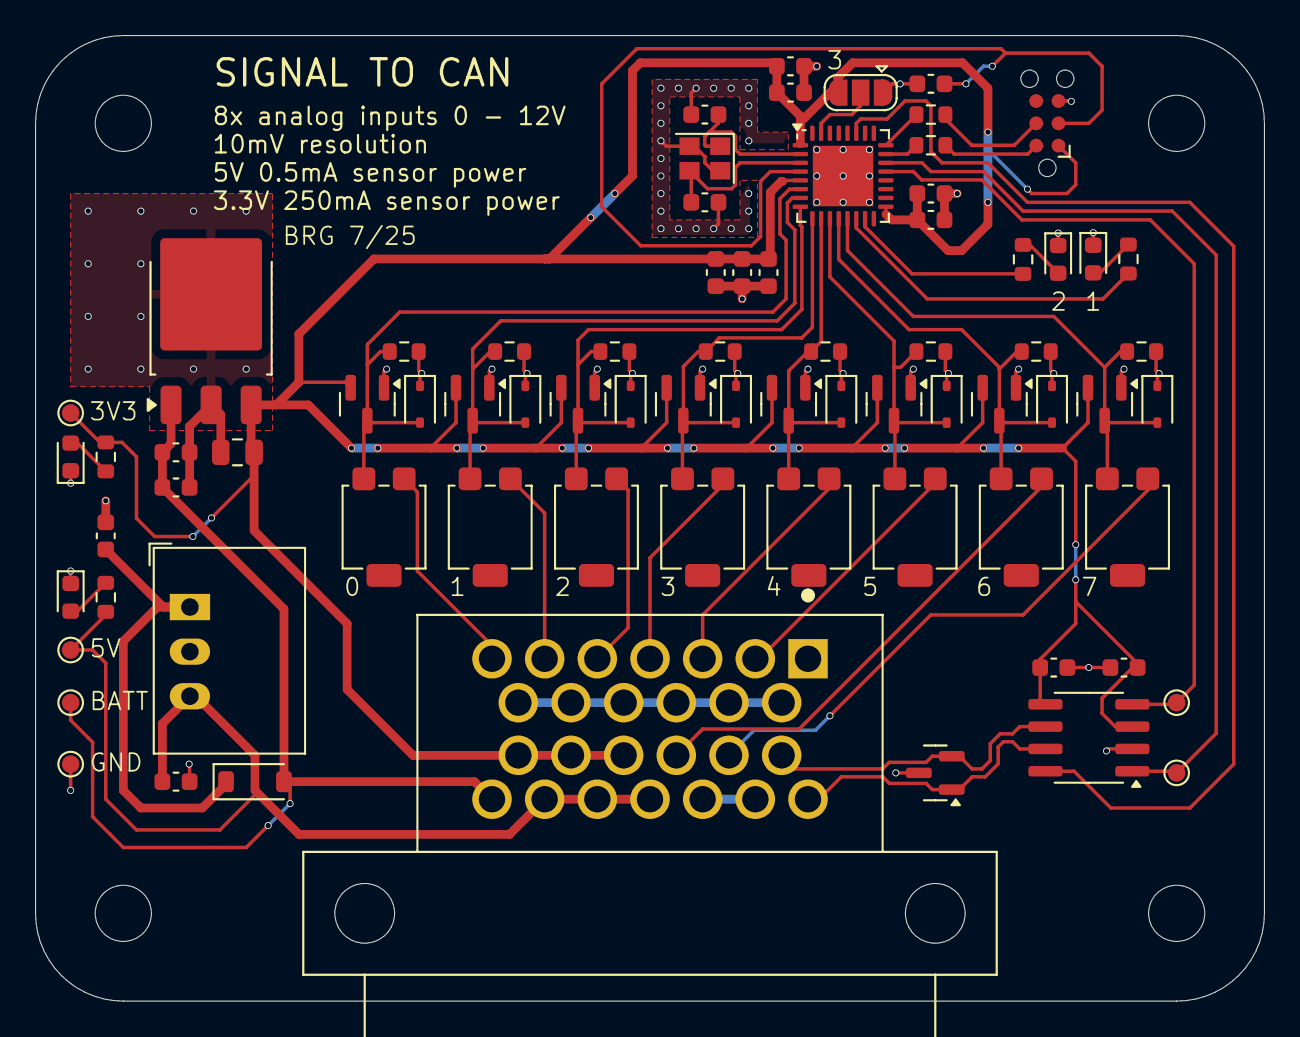
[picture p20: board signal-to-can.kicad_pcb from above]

Board: 2 copper layers, 70.0 x 55.0 mm, 79 parts (0 on the bottom side), 40 nets.

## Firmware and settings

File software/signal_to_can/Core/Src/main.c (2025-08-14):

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
/* Includes ------------------------------------------------------------------*/
#include "main.h"

/* USER CODE BEGIN Includes */
#include <stdbool.h>
#include <string.h>
#include <math.h>
#include "can_module.h"
#include "adc_module.h"
#include "process_signals.h"
/* USER CODE END Includes */

/* USER CODE BEGIN PTD */
typedef struct {
	volatile HAL_StatusTypeDef last_tx_status; /* return from CAN_Module_Send */
	volatile uint32_t last_hal_error; /* HAL_CAN_GetError() */
	volatile uint32_t last_esr; /* CAN->ESR snapshot */
	volatile uint32_t last_tsr; /* CAN->TSR snapshot */
	volatile uint32_t tx_ok_count; /* TX mailbox complete count */
	volatile uint32_t tx_error_count; /* HAL error callback count */
} can_debug_t;

extern can_debug_t g_can_dbg;
/* USER CODE END PTD */

/* USER CODE BEGIN PD */

// Heart beat
#define HEARTBEAT_INTERVAL_MS 500

// CAN bus

// ADC

// Test
#define TEST_CAN_ID 0x124
#define TEST_SEND_INTERVAL_MS    1000u
/* USER CODE END PD */

ADC_HandleTypeDef hadc;
DMA_HandleTypeDef hdma_adc;

CAN_HandleTypeDef hcan;

/* USER CODE BEGIN PV */

// Heart beat
static uint32_t heartbeat_tick = 0;

// CAN bus
uint32_t baud_enum = 2; // 2 -> 500 kbps

// Logic
uint32_t sample_period = 20; // sample at 50 Hz
uint32_t timeout_period = 10;


// Test
can_debug_t g_can_dbg = { 0 };
static uint32_t last_tick = 0;

/* USER CODE END PV */

void SystemClock_Config(void);
static void MX_GPIO_Init(void);
static void MX_DMA_Init(void);
static void MX_CAN_Init(void);
static void MX_ADC_Init(void);
/* USER CODE BEGIN PFP */

void Heartbeat_Task(void);
static void Test_Can_Task(uint16_t value);

/* USER CODE END PFP */

/**
  * @brief  The application entry point.
  * @retval int
  */
int main(void)
{

  /* MCU Configuration--------------------------------------------------------*/

  /* Reset of all peripherals, Initializes the Flash interface and the Systick. */
  HAL_Init();

  /* Configure the system clock */
  SystemClock_Config();

  /* Initialize all configured peripherals */
  MX_GPIO_Init();
  MX_DMA_Init();
  MX_CAN_Init();
  MX_ADC_Init();
  /* USER CODE BEGIN 2 */

	// Set Standby Pin on CAN transceiver low (normal mode) before initializing
	HAL_GPIO_WritePin(GPIOB, CAN_STANDBY_Pin, GPIO_PIN_RESET);

	if (CAN_Module_Init(&hcan, baud_enum) != HAL_OK) {
		// TODO
		Error_Handler();
	}

	// Start the bare-bones ADC module
	if (ADC_Module_Init(&hadc) != HAL_OK) {
		// TODO
	}

	Process_Signals_Init();

	last_tick = HAL_GetTick();
	heartbeat_tick = last_tick;
  /* USER CODE END 2 */

  /* Infinite loop */
  /* USER CODE BEGIN WHILE */
  while (1)
  {
    /* USER CODE END WHILE */

    /* USER CODE BEGIN 3 */
	  Heartbeat_Task();
	  Process_Signals_Update();
	  Process_Signals_Send_Can_If_Due(sample_period, timeout_period);
  }
  /* USER CODE END 3 */
}

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
/* USER CODE BEGIN 4 */

void Heartbeat_Task(void) {
	/* Check if enough time has passed */
	if ((HAL_GetTick() - heartbeat_tick) >= HEARTBEAT_INTERVAL_MS) {
		/* Toggle the LED */
		HAL_GPIO_TogglePin(GPIOB, LED_STATUS_1_Pin); // Example: Port B

		/* Update last toggle time */
		heartbeat_tick = HAL_GetTick();
	}
}

/**
 * @brief Periodically send a simple CAN test message and flash LED on success.
 *        Note: Updated to use CAN_Module_Send_Std() from can_module.c.
 */
static void Test_Can_Task(uint16_t value) {
	uint32_t now = HAL_GetTick();
	if ((now - last_tick) < TEST_SEND_INTERVAL_MS) {
		return;
	}
	last_tick = now;

	/* Minimal 1-byte test payload (kept as-is). */
	uint8_t data[2] = {(uint8_t)((value >> 8) & 0xFFu), (uint8_t)(value & 0xFFu)};


	/* Short TX timeout so we don't block the task loop. */
	const uint32_t tx_timeout_ms = 10u;

	/* Updated call: (std_id, data_ptr, dlc, timeout_ms). */
	HAL_StatusTypeDef st = CAN_Module_Send_Std(TEST_CAN_ID, data, 2u, tx_timeout_ms);

	g_can_dbg.last_tx_status = st;
	g_can_dbg.last_hal_error = HAL_CAN_GetError(&hcan);
	g_can_dbg.last_esr = hcan.Instance->ESR;
	g_can_dbg.last_tsr = hcan.Instance->TSR;

	if (st == HAL_OK) {
		HAL_GPIO_TogglePin(GPIOB, LED_STATUS_2_Pin);
	}
}

/* Called when a mailbox actually finishes transmitting */
void HAL_CAN_TxMailbox0CompleteCallback(CAN_HandleTypeDef *h) {
	(void) h;
	g_can_dbg.tx_ok_count++;
}

void HAL_CAN_TxMailbox1CompleteCallback(CAN_HandleTypeDef *h) {
	(void) h;
	g_can_dbg.tx_ok_count++;
}

void HAL_CAN_TxMailbox2CompleteCallback(CAN_HandleTypeDef *h) {
	(void) h;
	g_can_dbg.tx_ok_count++;
}

/* Called on any CAN error (ACK error, bus-off, etc.) */
void HAL_CAN_ErrorCallback(CAN_HandleTypeDef *h) {
	g_can_dbg.last_hal_error = HAL_CAN_GetError(h);
	g_can_dbg.last_esr = h->Instance->ESR; /* includes TEC/REC/LEC */
	g_can_dbg.last_tsr = h->Instance->TSR;
	g_can_dbg.tx_error_count++;
}

/* USER CODE END 4 */
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


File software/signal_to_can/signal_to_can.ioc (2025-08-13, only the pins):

Mcu.UserName=STM32F042K6Tx
PA0.Signal=ADC_IN0
PA1.Signal=ADC_IN1
PA11.Signal=CAN_RX
PA12.Signal=CAN_TX
PA13.Signal=SYS_SWDIO
PA14.Signal=SYS_SWCLK
PA2.Signal=ADC_IN2
PA3.Signal=ADC_IN3
PA4.Signal=ADC_IN4
PA5.Signal=ADC_IN5
PA6.Signal=ADC_IN6
PA7.Signal=ADC_IN7
PB0.GPIO_Label=LED_STATUS_1
PB0.Signal=GPIO_Output
PB1.GPIO_Label=LED_STATUS_2
PB1.Signal=GPIO_Output
PB4.GPIO_Label=CAN_STANDBY
PB4.Signal=GPIO_Output
PF0-OSC_IN.Signal=RCC_OSC_IN
PF1-OSC_OUT.Signal=RCC_OSC_OUT

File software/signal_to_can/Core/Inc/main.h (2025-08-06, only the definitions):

#define LED_STATUS_1_Pin GPIO_PIN_0
#define LED_STATUS_1_GPIO_Port GPIOB
#define LED_STATUS_2_Pin GPIO_PIN_1
#define LED_STATUS_2_GPIO_Port GPIOB
#define CAN_STANDBY_Pin GPIO_PIN_4
#define CAN_STANDBY_GPIO_Port GPIOB

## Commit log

2025-07-21 AFE, power supply, connector
    Ready for PCB layout
    [analog_front_end.kicad_sch, power_supply_3v3_400ma_40V_protected.kicad_sch, signal-to-can.kicad_sch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]
2025-07-22 1st rev PCB layout
    [analog_front_end.kicad_sch, can_transciever_no_term.kicad_sch, power_supply_3v3_400ma_40V_protected.kicad_sch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]
2025-07-22 production v1
    [amp_superseal_9-6437287-8.step, signal-to-can.kicad_pcb, signal-to-can.kicad_sch]
2025-08-06 Initial firmware
    - poll ADCs and send converted messages at a given rate
    - config message to enable / disable inputs and adjust scaling factors.
    [analog_front_end.kicad_sch, power_supply_3v3_400ma_40V_protected.kicad_sch, signal-to-can.step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]
2025-08-12 Working CAN peripheral
    - heartbeat
    - test can message
    - adc module compiling
    [stm32f042k6ux.kicad_sch]
2025-08-13 ADC configuration
    - updated README
    Todo:
    - fix potentiometer wiring in schematic
    - add divider test points
    - bigger ground test point
    - Fix tranceiver Vdd (should be 5V)
    - find a new trim pot with more turns (better accuracy)
    - investigate powering of 3V3 via backfeed from ADC (clamp diodes or the ADC input on the MCU)
    [adc_module.c, main.c]
2025-08-13 Use DMA & Scan mode for ADC module
    - verified test works
2025-08-14 Updated CAD
    - easier to print on side for ASA
    - accounted for thru hole pins
    - fixed issue with lid and assembly around connector
    [base.step, base.stl, lid.step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]
2025-08-14 Message processing module
    business logic for device on top of peripheral drivers

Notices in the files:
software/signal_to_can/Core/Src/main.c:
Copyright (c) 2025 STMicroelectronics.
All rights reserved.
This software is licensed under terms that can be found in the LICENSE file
